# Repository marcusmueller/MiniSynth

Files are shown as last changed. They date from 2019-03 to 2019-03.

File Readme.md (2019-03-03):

# MiniSynth

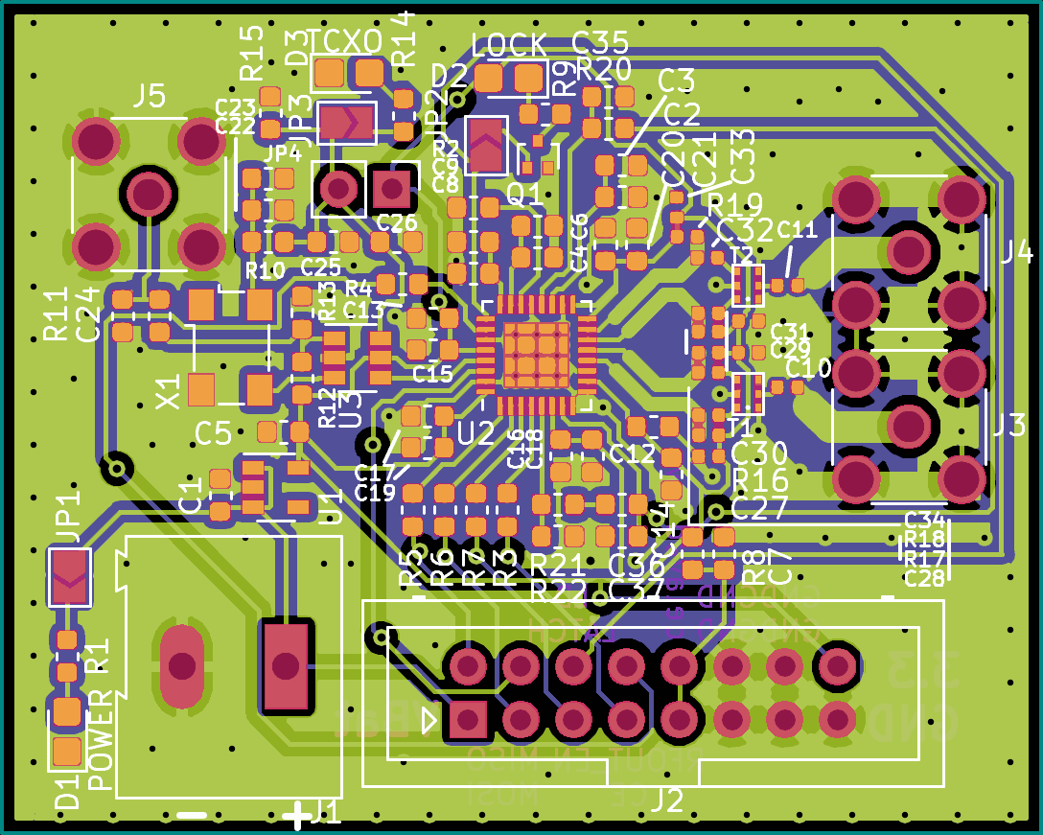
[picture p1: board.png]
Top View on Gerbers


A small, MAX2870-based synthesizer with integrated oscillator or selectable
external reference clock input.

Done in KiCad.

Central components:

* Maxim MAX2870: Fractional-N Synthesizer
* Anaren B0430J50100AHF: Wideband Balun to convert MAX2870's differential output(s) to single-ended
* FOX924B: 16 MHz Oscillator
* The tears of a million coffee beans

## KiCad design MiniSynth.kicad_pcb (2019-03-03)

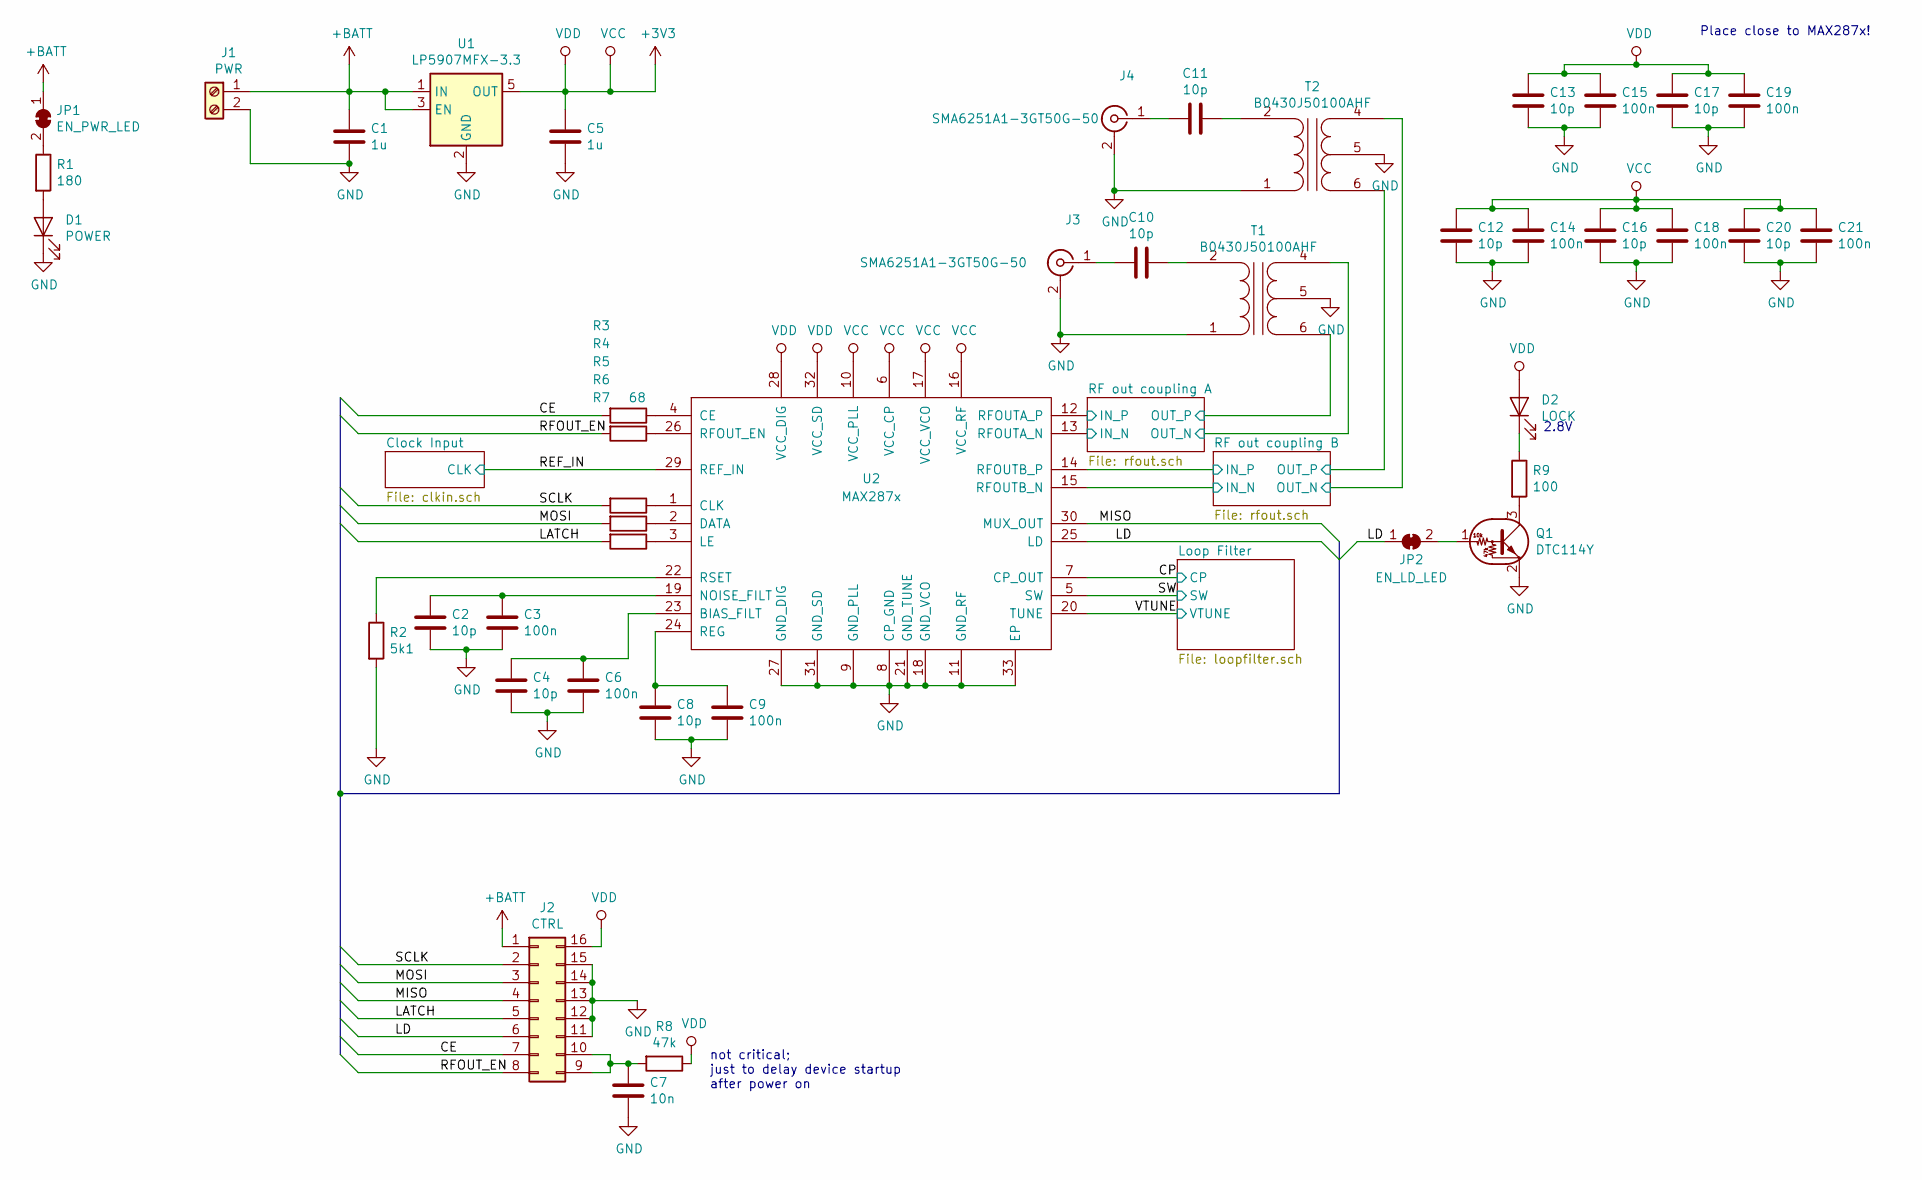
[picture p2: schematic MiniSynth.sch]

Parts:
C1, C5: 1u; C_0603_1608Metric
C2, C4, C8, C12, C13, C16, C17, C20: 10p; C_0603_1608Metric
C3, C6, C9, C14, C15, C18, C19, C21: 100n; C_0603_1608Metric
C7: 10n; C_0603_1608Metric
C10, C11: 10p; C_0402_1005Metric
D1: POWER; LED_0805_2012Metric_Castellated
D2: LOCK; LED_0805_2012Metric_Castellated
J1: PWR; TerminalBlock_Altech_AK300-2_P5.00mm
J2: CTRL; Multicomp_MC9A12-1634_2x08_P2.54mm_Vertical
J3, J4: SMA6251A1-3GT50G-50; SMA_Amphenol_132134-16_Vertical
JP1: EN_PWR_LED; SolderJumper-2_P1.3mm_Open_TrianglePad1.0x1.5mm
JP2: EN_LD_LED; SolderJumper-2_P1.3mm_Open_TrianglePad1.0x1.5mm
Q1: DTC114Y; SOT-416
R1: 180; R_0603_1608Metric
R2: 5k1; R_0603_1608Metric
R3, R4, R5, R6, R7: 68; R_0603_1608Metric
R8: 47k; R_0603_1608Metric
R9: 100; R_0603_1608Metric
T1, T2: B0430J50100AHF
U1: LP5907MFX-3.3; SOT-23-5
U2: MAX287x; QFN-32-1EP_5x5mm_P0.5mm_EP3.1x3.1mm_ThermalVias

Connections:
+3V3: C5.1, C12.2, C13.2, C14.2, C15.2, C16.2, C17.2, C18.2, C19.2, C20.2, C21.2, D2.2 (A), J2.16, R8.1, U1.5 (OUT), U2.6 (VCC_CP), U2.10 (VCC_PLL), U2.16 (VCC_RF), U2.17 (VCC_VCO), U2.28 (VCC_DIG), U2.32 (VCC_SD); also elsewhere on the board
+BATT: C1.1, J1.1, J2.1, JP1.1 (A), U1.1 (IN), U1.3 (EN)
/CE: J2.7, R3.2
/CP: U2.7 (CP_OUT); also elsewhere on the board
/LATCH: J2.5, R7.2
/LD: J2.6, JP2.1 (A), U2.25 (LD)
/MISO: J2.4, U2.30 (MUX_OUT)
/MOSI: J2.3, R6.2
/REF_IN: U2.29 (REF_IN); also elsewhere on the board
/RF out coupling A/IN_N: U2.13 (RFOUTA_N); also elsewhere on the board
/RF out coupling A/IN_P: U2.12 (RFOUTA_P); also elsewhere on the board
/RF out coupling A/OUT_N: T1.4 (BAL1); also elsewhere on the board
/RF out coupling A/OUT_P: T1.6 (BAL2); also elsewhere on the board
/RF out coupling B/IN_N: U2.15 (RFOUTB_N); also elsewhere on the board
/RF out coupling B/IN_P: U2.14 (RFOUTB_P); also elsewhere on the board
/RF out coupling B/OUT_N: T2.4 (BAL1); also elsewhere on the board
/RF out coupling B/OUT_P: T2.6 (BAL2); also elsewhere on the board
/RFOUT_EN: J2.8, R4.2
/SCLK: J2.2, R5.2
/SW: U2.5 (SW); also elsewhere on the board
/VTUNE: U2.20 (TUNE); also elsewhere on the board
GND: C1.2, C2.1, C3.1, C4.1, C5.2, C6.1, C7.2, C8.1, C9.1, C12.1, C13.1, C14.1, C15.1, C16.1, C17.1, C18.1, C19.1, C20.1, C21.1, D1.1 (K), J1.2, J2.11, J2.12, J2.13, J2.14, J2.15, J3.2 (Ext), J4.2 (Ext), Q1.2 (E), R2.2, T1.1 (GND), T1.3 (GND), T1.5, T2.1 (GND), T2.3 (GND), T2.5, U1.2 (GND), U2.8 (CP_GND), U2.9 (GND_PLL), U2.11 (GND_RF), U2.18 (GND_VCO), U2.21 (GND_TUNE), U2.27 (GND_DIG), U2.31 (GND_SD), U2.33 (EP); also elsewhere on the board
unnamed: C2.2, C3.2, U2.19 (NOISE_FILT)
unnamed: C4.2, C6.2, U2.23 (BIAS_FILT)
unnamed: C7.1, J2.9, J2.10, R8.2
unnamed: C8.2, C9.2, U2.24 (REG)
unnamed: C10.1, T1.2 (UNB)
unnamed: C10.2, J3.1 (In)
unnamed: C11.1, T2.2 (UNB)
unnamed: C11.2, J4.1 (In)
unnamed: D1.2 (A), R1.2
unnamed: D2.1 (K), R9.1
unnamed: JP1.2 (B), R1.1
unnamed: JP2.2 (B), Q1.1 (B)
unnamed: Q1.3 (C), R9.2
unnamed: R2.1, U2.22 (RSET)
unnamed: R3.1, U2.4 (CE)
unnamed: R4.1, U2.26 (RFOUT_EN)
unnamed: R5.1, U2.1 (CLK)
unnamed: R6.1, U2.2 (DATA)
unnamed: R7.1, U2.3 (LE)

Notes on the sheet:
2.8V
not critical; just to delay device startup after power on
Place close to MAX287x!

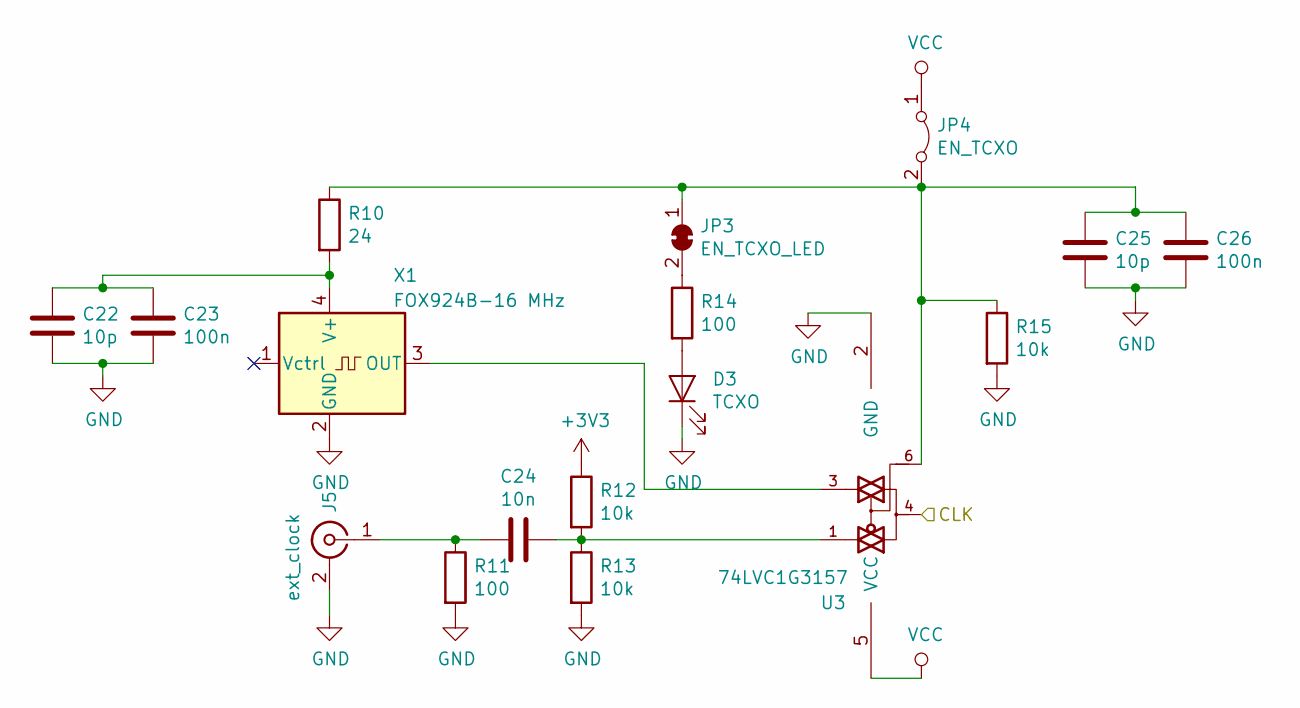
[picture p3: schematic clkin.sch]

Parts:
C22, C25: 10p; C_0603_1608Metric
C23, C26: 100n; C_0603_1608Metric
C24: 10n; C_0603_1608Metric
D3: TCXO; LED_0805_2012Metric_Castellated
J5: ext_clock; SMA_Amphenol_132134-16_Vertical
JP3: EN_TCXO_LED; SolderJumper-2_P1.3mm_Open_TrianglePad1.0x1.5mm
JP4: EN_TCXO; PinHeader_1x02_P2.54mm_Vertical
R10: 24; R_0603_1608Metric
R11, R14: 100; R_0603_1608Metric
R12, R13, R15: 10k; R_0603_1608Metric
U3: 74LVC1G3157; SOT-23-6
X1: FOX924B-16 MHz; Oscillator_SMD_Fordahl_DFAS15-4Pin_5.0x3.2mm

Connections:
+3V3: JP4.1 (A), R12.1, U3.5 (VCC); also elsewhere on the board
/REF_IN: U3.4; also elsewhere on the board
GND: C22.1, C23.1, C25.1, C26.1, D3.1 (K), J5.2 (Ext), R11.2, R13.2, R15.2, U3.2 (GND), X1.2 (GND); also elsewhere on the board
unnamed: C22.2, C23.2, R10.2, X1.4 (V+)
unnamed: C24.1, R12.2, R13.1, U3.1
unnamed: C24.2, J5.1 (In), R11.1
unnamed: C25.2, C26.2, JP3.1 (A), JP4.2 (B), R10.1, R15.1, U3.6
unnamed: D3.2 (A), R14.2
unnamed: JP3.2 (B), R14.1
unnamed: U3.3, X1.3 (OUT)

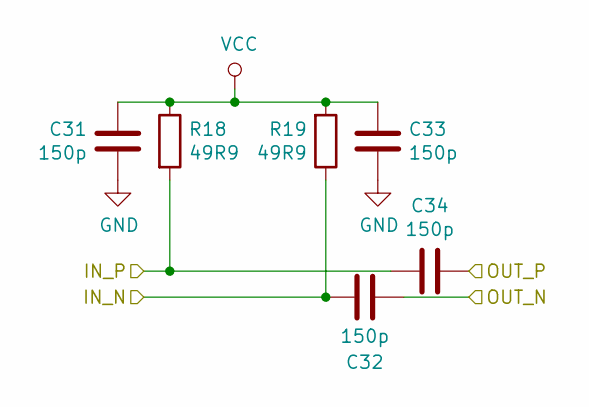
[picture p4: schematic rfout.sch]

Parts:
C27, C28, C29, C30: 150p; C_0402_1005Metric
R16, R17: 49R9; R_0402_1005Metric

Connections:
+3V3: C27.2, C29.1, R16.1, R17.2; also elsewhere on the board
/RF out coupling A/IN_N: C28.1, R17.1; also elsewhere on the board
/RF out coupling A/IN_P: C30.1, R16.2; also elsewhere on the board
/RF out coupling A/OUT_N: C28.2; also elsewhere on the board
/RF out coupling A/OUT_P: C30.2; also elsewhere on the board
GND: C27.1, C29.2; also elsewhere on the board

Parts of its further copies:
C31, C32, C33, C34: 150p; C_0402_1005Metric
R18, R19: 49R9; R_0402_1005Metric

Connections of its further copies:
+3V3: C31.2, C33.1, R18.1, R19.2; also elsewhere on the board
/RF out coupling B/IN_N: C32.1, R19.1; also elsewhere on the board
/RF out coupling B/IN_P: C34.1, R18.2; also elsewhere on the board
/RF out coupling B/OUT_N: C32.2; also elsewhere on the board
/RF out coupling B/OUT_P: C34.2; also elsewhere on the board
GND: C31.1, C33.2; also elsewhere on the board

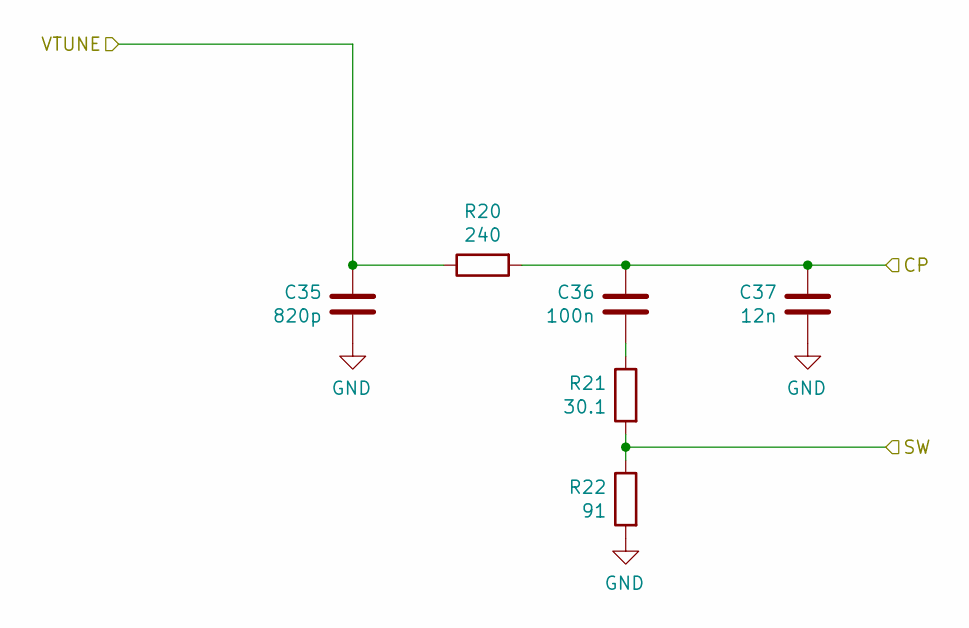
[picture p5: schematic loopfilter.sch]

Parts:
C35: 820p; C_0603_1608Metric
C36: 100n; C_0603_1608Metric
C37: 12n; C_0603_1608Metric
R20: 240; R_0603_1608Metric
R21: 30.1; R_0603_1608Metric
R22: 91; R_0603_1608Metric

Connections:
/CP: C36.1, C37.1, R20.2; also elsewhere on the board
/SW: R21.2, R22.1; also elsewhere on the board
/VTUNE: C35.1, R20.1; also elsewhere on the board
GND: C35.2, C37.2, R22.2; also elsewhere on the board
unnamed: C36.2, R21.1

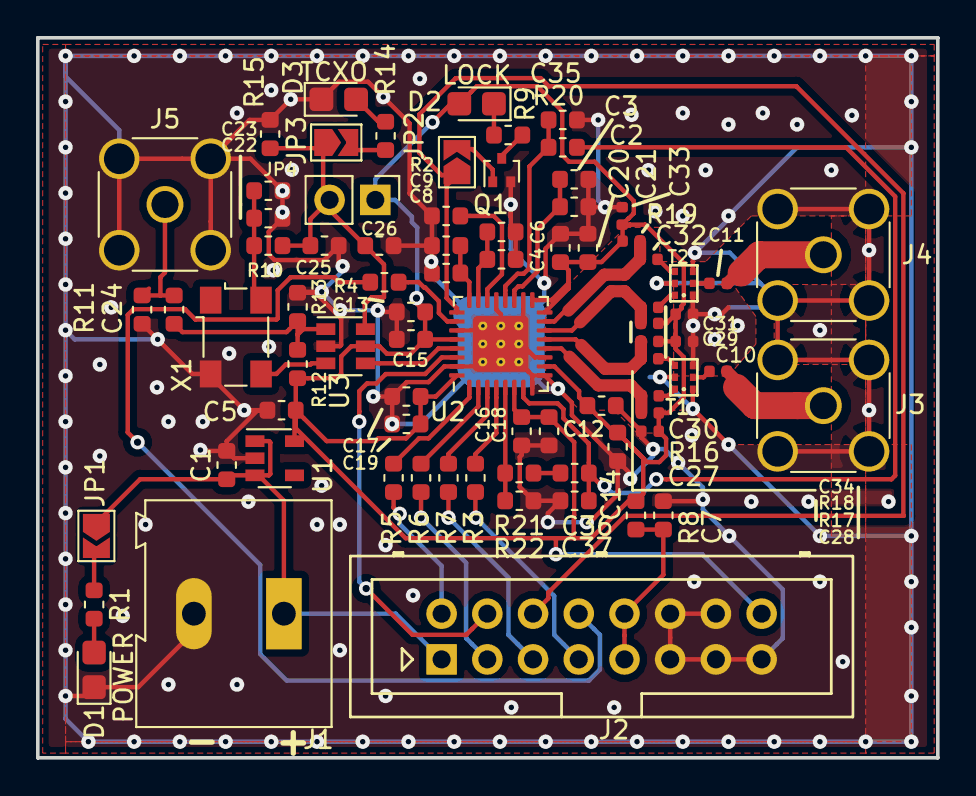
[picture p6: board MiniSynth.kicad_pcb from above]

Board: 2 copper layers, 50.0 x 40.0 mm, 78 parts (0 on the bottom side), 49 nets.

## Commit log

2019-03-03 added analog switch symbol with explicit power pins (ugly)
2019-03-03 Balun Footprint
